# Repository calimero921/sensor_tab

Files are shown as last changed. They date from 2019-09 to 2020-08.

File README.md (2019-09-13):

# sensor_tab
ESP32 sensor tab

External libraries : 
* BLEDevice
* BLEServer
* BLEUtils
* BLE2902
* NDEF: utility class to translate NDEF format of rfid card data (updated and corrected)
* Adafruit_NeoPixel: utility class to manage WS2812 led

Internal libraries : 
* cardReader: wrapper for MFRC522 library mixed with HW-178 multiplexing componenent
* readerState: data and utility class to manage reader state based on rfidData class
* rfidData: data and utility class to manage rfid card information
* pixelManager: wrapper for Adafruit Neo Pixel library to manage the set on WS2812 led, based on readerState library

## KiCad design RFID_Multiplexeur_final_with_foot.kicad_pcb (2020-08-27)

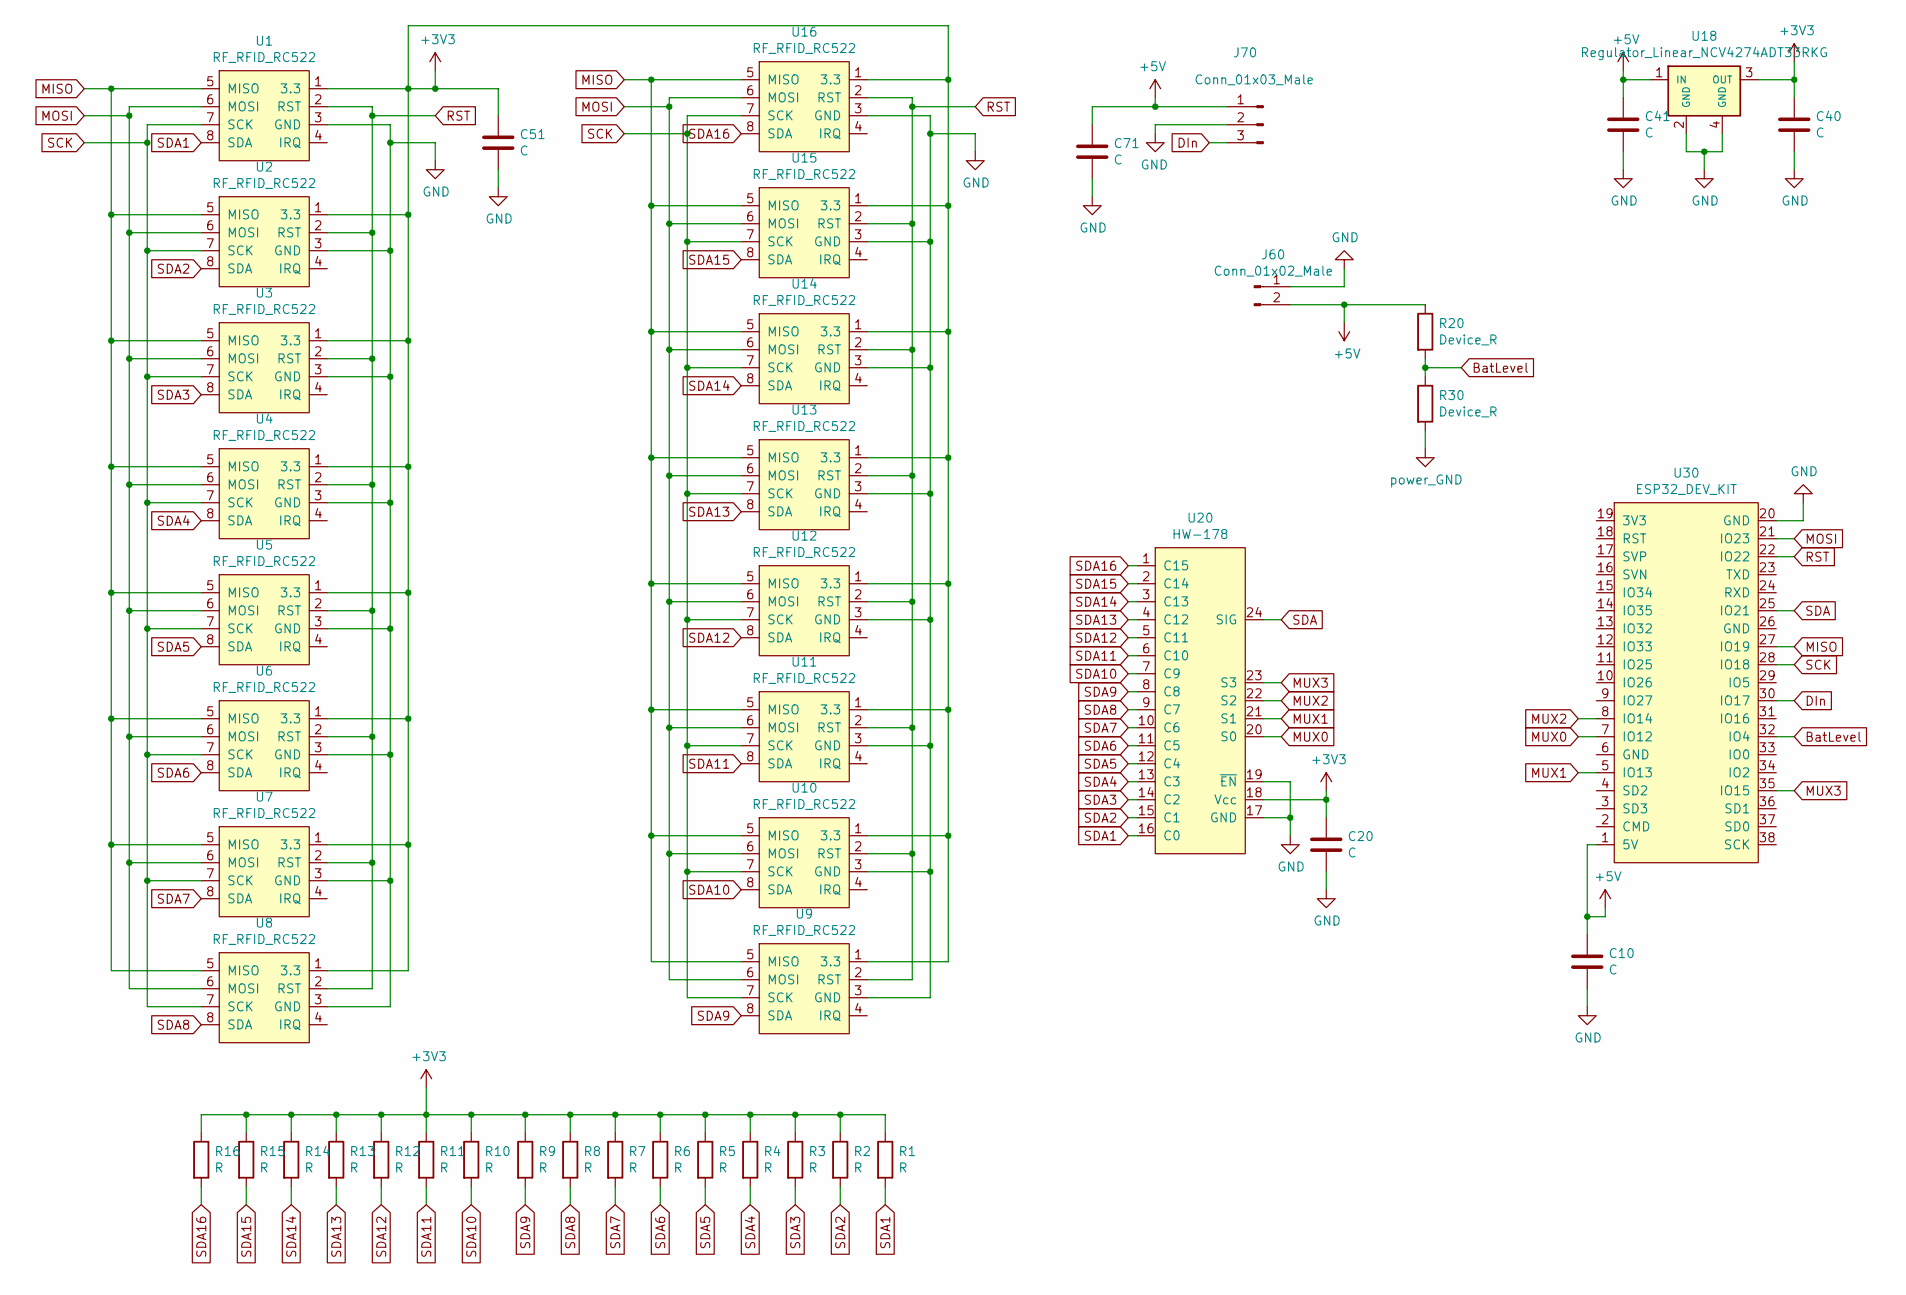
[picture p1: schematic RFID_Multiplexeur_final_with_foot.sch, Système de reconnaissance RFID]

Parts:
C10, C20, C71: C; CP_Radial_D10.0mm_P5.00mm
C40, C41, C51: C; CP_220uF_Eirbot
J60: Conn_01x02_Male; TerminalBlock_bornier-2_P5.08mm
J70: Conn_01x03_Male; JST_PH_S3B-PH-K_1x03_P2.00mm_Horizontal
R1, R2, R3, R4, R5, R6, R7, R8, R9, R10, R11, R12, R13, R14, R15, R16: R; R_Axial_DIN0309_L9.0mm_D3.2mm_P15.24mm_Horizontal
R20, R30: Device_R; R_Axial_DIN0309_L9.0mm_D3.2mm_P15.24mm_Horizontal
U1, U2, U3, U4, U5, U6, U7, U8, U9, U10, U11, U12, U13, U14, U15, U16: RF_RFID_RC522; JST_PH_B8B-PH-SM4-TB_1x08-1MP_P2.00mm_Vertical
U18: Regulator_Linear_NCV4274ADT33RKG; TO-252-3_TabPin4
U20: HW-178; HP4067_Demultiplexer
U30: ESP32_DEV_KIT

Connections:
+3V3: C20.1, C40.1, C51.1, R1.1, R2.1, R3.1, R4.1, R5.1, R6.1, R7.1, R8.1, R9.1, R10.1, R11.1, R12.1, R13.1, R14.1, R15.1, R16.1, U1.1 (3.3), U2.1 (3.3), U3.1 (3.3), U4.1 (3.3), U5.1 (3.3), U6.1 (3.3), U7.1 (3.3), U8.1 (3.3), U9.1 (3.3), U10.1 (3.3), U11.1 (3.3), U12.1 (3.3), U13.1 (3.3), U14.1 (3.3), U15.1 (3.3), U16.1 (3.3), U18.3 (OUT), U20.18 (Vcc); also elsewhere on the board
+5V: C10.1, C41.1, C71.1, J60.2, J70.1, R20.1, U18.1 (IN), U30.1 (5V)
BatLevel: R20.2, R30.1, U30.32 (IO4)
DIn: J70.3, U30.30 (IO17)
MISO: U1.5 (MISO), U2.5 (MISO), U3.5 (MISO), U4.5 (MISO), U5.5 (MISO), U6.5 (MISO), U7.5 (MISO), U8.5 (MISO), U9.5 (MISO), U10.5 (MISO), U11.5 (MISO), U12.5 (MISO), U13.5 (MISO), U14.5 (MISO), U15.5 (MISO), U16.5 (MISO), U30.27 (IO19); also elsewhere on the board
MOSI: U1.6 (MOSI), U2.6 (MOSI), U3.6 (MOSI), U4.6 (MOSI), U5.6 (MOSI), U6.6 (MOSI), U7.6 (MOSI), U8.6 (MOSI), U9.6 (MOSI), U10.6 (MOSI), U11.6 (MOSI), U12.6 (MOSI), U13.6 (MOSI), U14.6 (MOSI), U15.6 (MOSI), U16.6 (MOSI), U30.21 (IO23); also elsewhere on the board
MUX0: U20.20 (S0), U30.7 (IO12)
MUX1: U20.21 (S1), U30.5 (IO13)
MUX2: U20.22 (S2), U30.8 (IO14)
MUX3: U20.23 (S3), U30.35 (IO15)
RST: U1.2 (RST), U2.2 (RST), U3.2 (RST), U4.2 (RST), U5.2 (RST), U6.2 (RST), U7.2 (RST), U8.2 (RST), U9.2 (RST), U10.2 (RST), U11.2 (RST), U12.2 (RST), U13.2 (RST), U14.2 (RST), U15.2 (RST), U16.2 (RST), U30.22 (IO22); also elsewhere on the board
SCK: U1.7 (SCK), U2.7 (SCK), U3.7 (SCK), U4.7 (SCK), U5.7 (SCK), U6.7 (SCK), U7.7 (SCK), U8.7 (SCK), U9.7 (SCK), U10.7 (SCK), U11.7 (SCK), U12.7 (SCK), U13.7 (SCK), U14.7 (SCK), U15.7 (SCK), U16.7 (SCK), U30.28 (IO18); also elsewhere on the board
SDA: U20.24 (SIG), U30.25 (IO21)
SDA1: R1.2, U1.8 (SDA), U20.16 (C0)
SDA2: R2.2, U2.8 (SDA), U20.15 (C1)
SDA3: R3.2, U3.8 (SDA), U20.14 (C2)
SDA4: R4.2, U4.8 (SDA), U20.13 (C3)
SDA5: R5.2, U5.8 (SDA), U20.12 (C4)
SDA6: R6.2, U6.8 (SDA), U20.11 (C5)
SDA7: R7.2, U7.8 (SDA), U20.10 (C6)
SDA8: R8.2, U8.8 (SDA), U20.9 (C7); also elsewhere on the board
SDA9: R9.2, U9.8 (SDA), U20.8 (C8)
SDA10: R10.2, U10.8 (SDA), U20.7 (C9)
SDA11: R11.2, U11.8 (SDA), U20.6 (C10); also elsewhere on the board
SDA12: R12.2, U12.8 (SDA), U20.5 (C11)
SDA13: R13.2, U13.8 (SDA), U20.4 (C12)
SDA14: R14.2, U14.8 (SDA), U20.3 (C13)
SDA15: R15.2, U15.8 (SDA), U20.2 (C14)
SDA16: R16.2, U16.8 (SDA), U20.1 (C15)

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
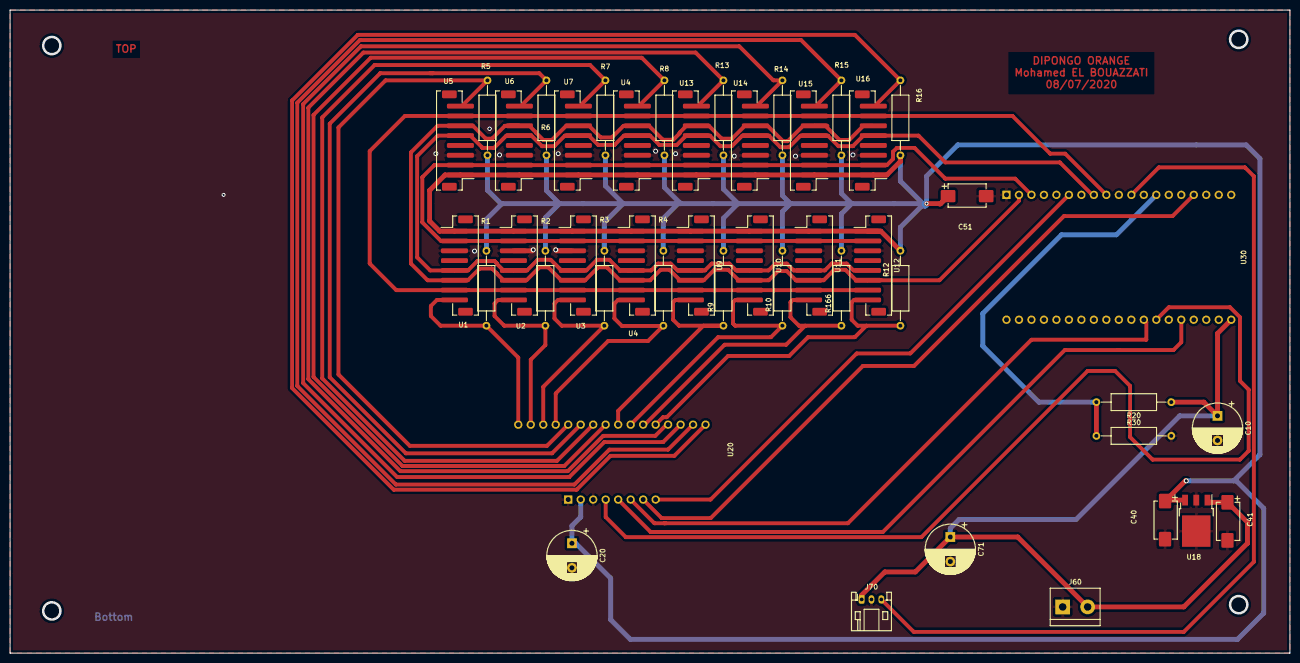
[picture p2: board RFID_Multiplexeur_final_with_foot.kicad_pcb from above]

Board: 2 copper layers, 260.4 x 130.8 mm, 45 parts (0 on the bottom side), 30 nets.

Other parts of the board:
R166: R; R_Axial_DIN0309_L9.0mm_D3.2mm_P15.24mm_Horizontal
U4#2: RF_RFID_RC522; JST_PH_B8B-PH-SM4-TB_1x08-1MP_P2.00mm_Vertical

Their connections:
+3V3: R166.1, U4#2.1; also elsewhere on the board
MISO: U4#2.5; also elsewhere on the board
MOSI: U4#2.6; also elsewhere on the board
RST: U4#2.2; also elsewhere on the board
SCK: U4#2.7; also elsewhere on the board
SDA8: U4#2.8; also elsewhere on the board
SDA11: R166.2; also elsewhere on the board

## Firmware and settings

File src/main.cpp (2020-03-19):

/*
*/

#include <Arduino.h>
#include <BLEDevice.h>
#include <BLEServer.h>
#include <BLEUtils.h>
#include <BLE2902.h>

#include "main.h"
#include "cardReader.h"
#include "rfidData.h"
#include "pixelManager.h"
#include "readerState.h"

BLEServer *pServer = NULL;
BLECharacteristic *pLedCharacteristic = NULL;
BLECharacteristic *pRfidCharacteristic = NULL;
bool deviceConnected = false;
bool oldDeviceConnected = false;
uint32_t value = 0;

int manufacturer_code = 0xFFFF;
char manufacturer_name[] = "DIPONGO";
char device_name[] = "DIPONGO-TAB-ESP32";

// Configuration readerState
ReaderState readerState = ReaderState(MFRC522COUNT);

// Configuration Adafruit_NeoPixel
// Adafruit_NeoPixel pixels(PIXELNUMBER, PIXELDATAPIN, NEO_GRB + NEO_KHZ800);
PixelManager pixelStrip = PixelManager(PIXELCOUNT);

// Configuration MFRC522
CardReader cardReader = CardReader(MFRC522COUNT);

BLEAdvertisementData advertisement;
BLEAdvertising *pAdvertising;

class MyServerCallbacks : public BLEServerCallbacks
{
  void onConnect(BLEServer *pServer)
  {
    deviceConnected = true;
    BLEDevice::startAdvertising();
  };

  void onDisconnect(BLEServer *pServer)
  {
    deviceConnected = false;
  }
};

class LedCharacteristicCallbacks : public BLECharacteristicCallbacks
{
  void onRead(BLECharacteristic *pCharacteristic)
  {
    String jsonString = readerState.toJsonString(true, false);
    uint16_t arraySize = jsonString.length();
    char results[arraySize];
    jsonString.toCharArray(results, arraySize);
    pCharacteristic->setValue(results);
  }

  void onWrite(BLECharacteristic *pCharacteristic)
  {
    std::string value = pCharacteristic->getValue();
    Serial.print("Received Value: ");
    for (int i = 0; i < value.length(); i++)
      Serial.print(value[i]);
    Serial.println();
  }
};

class RfidCharacteristicCallbacks : public BLECharacteristicCallbacks
{
  void onRead(BLECharacteristic *pCharacteristic)
  {
    String jsonString = readerState.toJsonString(true, true);
    uint16_t arraySize = jsonString.length();
    char results[arraySize];
    jsonString.toCharArray(results, arraySize);
    pCharacteristic->setValue(results);
  }
};

void setup()
{
  Serial.begin(115200);
  Serial.println("Main::Setup");

  pixelStrip.init();
  pixelStrip.switchOffAllPixels();

  cardReader.init();

  // Create the BLE Device
  BLEDevice::init(device_name);

  // Create the BLE Server
  pServer = BLEDevice::createServer();
  pAdvertising = pServer->getAdvertising();

  String s;
  char b2 = (char)(manufacturer_code >> 8);
  manufacturer_code <<= 8;
  char b1 = (char)(manufacturer_code >> 8);
  s.concat(b1);
  s.concat(b2);
  s.concat(manufacturer_name);
  advertisement.setManufacturerData(s.c_str());
  advertisement.setName(device_name);
  pAdvertising->setAdvertisementData(advertisement);
  pServer->setCallbacks(new MyServerCallbacks());

  // Create the BLE Service
  BLEService *pService = pServer->createService(SERVICE_UUID);

  // Create a BLE led Characteristic
  pLedCharacteristic = pService->createCharacteristic(
      LED_CHARACTERISTIC_UUID,
      BLECharacteristic::PROPERTY_READ |
          BLECharacteristic::PROPERTY_WRITE |
          BLECharacteristic::PROPERTY_NOTIFY |
          BLECharacteristic::PROPERTY_INDICATE);
  // https://www.bluetooth.com/specifications/gatt/viewer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
  // Create a BLE Descriptor
  pLedCharacteristic->addDescriptor(new BLE2902());
  pLedCharacteristic->setCallbacks(new LedCharacteristicCallbacks());

  // Create a BLE led Characteristic
  pRfidCharacteristic = pService->createCharacteristic(
      RFID_CHARACTERISTIC_UUID,
      BLECharacteristic::PROPERTY_READ |
          BLECharacteristic::PROPERTY_NOTIFY |
          BLECharacteristic::PROPERTY_INDICATE);
  // https://www.bluetooth.com/specifications/gatt/viewer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
  // Create a BLE Descriptor
  pRfidCharacteristic->addDescriptor(new BLE2902());
  pRfidCharacteristic->setCallbacks(new RfidCharacteristicCallbacks());

  // Start the service
  pService->start();

  // Start advertising
  BLEAdvertising *pAdvertising = BLEDevice::getAdvertising();
  pAdvertising->addServiceUUID(SERVICE_UUID);
  pAdvertising->setScanResponse(false);
  pAdvertising->setMinPreferred(0x0); // set value to 0x00 to not advertise this parameter
  BLEDevice::startAdvertising();
  Serial.println("Main::Waiting a client connection to notify...");
}

void loop()
{
  // notify changed value
  if (deviceConnected)
  {
#ifdef DEBUG
    Serial.println("Main::Device connected...");
#endif
    boolean hasChanged = false;
    for (int reader = 0; reader < MFRC522COUNT; reader++)
    {
#ifdef DEBUG
      Serial.print("Main::Using reader ");
      Serial.print(reader);
      Serial.println(" ...");
#endif
      RfidData cardContent = cardReader.readRFIDCard(reader);
      // test if reader has content
      if (cardContent.error().length() == 0)
      {
        if (readerState.setState(reader, &cardContent))
        {
          hasChanged = true;
        }
      }
    }
    //pixelStrip.setPixelState(&readerState);

    if (hasChanged)
    {
      String jsonString = readerState.toJsonString(true, true);
      uint16_t arraySize = jsonString.length();
      char results[arraySize];
      jsonString.toCharArray(results, arraySize);

      Serial.print("Main::Notifying bluetooth master:");
      Serial.println(results);
      pRfidCharacteristic->setValue(results);
      pRfidCharacteristic->notify();
    }
    else
    {
#ifdef DEBUG
      Serial.println("Main::Nothing to notify...");
#endif
    }
    // delay(1000);
  }

  // disconnecting
  if (!deviceConnected && oldDeviceConnected)
  {
    Serial.println("Main::Device disconnecting...");
    delay(500); // give the bluetooth stack the chance to get things ready

    cardReader.shutdownAllReaders();
    pixelStrip.switchOffPixel(PIXELCOUNT - 1);

    pAdvertising->start();
    Serial.println("Main::Start advertising");
    oldDeviceConnected = deviceConnected;
  }
  // connecting
  if (deviceConnected && !oldDeviceConnected)
  {
    Serial.println("Main::Device connecting...");
    //pixelStrip.setPixelRGB(PIXELCOUNT - 1, 0, 32, 0);
    // do stuff here on connecting
    oldDeviceConnected = deviceConnected;
  }
}

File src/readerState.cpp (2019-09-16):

/*
*/

#include "readerState.h"

ReaderState::ReaderState(int nbCardReader)
{
    countCardReader = nbCardReader;
    readerState = (RfidData *)calloc(countCardReader, sizeof(RfidData));
    // Initialisation du tableau
    for(uint16_t i = 0; i < countCardReader; i++)
    {
        readerState[i] = RfidData();
    }
}

ReaderState::~ReaderState()
{
    free(readerState);
}

uint16_t ReaderState::count()
{
    return countCardReader;
}

boolean ReaderState::setState(uint16_t reader, RfidData *data)
{
#ifdef DEBUG
    Serial.println("ReaderState::setState:");
#endif
    boolean result = true;
    if (data->error().length() > 0)
    {
        // do not change state if an error occurs
        result = false;
    }
    else
    {
        if (readerState[reader].equals(data))
        {
            // do not change state if data is the same
            result = false;
        }
        else
        {
            // update state if data is different
            readerState[reader].set(data);
        }
    }
#ifdef DEBUG
    Serial.print("ReaderState::setState:return ");
    Serial.println(result);
#endif
    return result;
}

RfidData ReaderState::getState(uint16_t reader)
{
    return readerState[reader];
}

String ReaderState::toJsonString(boolean colorSelector, boolean formatSelector)
{
    StaticJsonDocument<1024> jsonArray;

    for (int reader = 0; reader < countCardReader; reader++)
    {
        StaticJsonDocument<256> jsonObject;
        jsonObject["reader"] = reader;
        if (colorSelector)
        {
            jsonObject["color"] = readerState[reader].color();
        }
        if (formatSelector)
        {
            jsonObject["format"] = readerState[reader].format();
        }
#ifdef DEBUG
        Serial.print("toJsonString::jsonObject -> ");
        serializeJson(jsonObject, Serial);
        Serial.println();
#endif
        jsonArray.add(jsonObject);
    }
    uint16_t arraySize = jsonArray.memoryUsage();
#ifdef DEBUG
    Serial.print("toJsonString::arraySize -> ");
    Serial.println(arraySize);
#endif
    char results[arraySize];
    serializeJson(jsonArray, results, arraySize);
#ifdef DEBUG
    Serial.print("toJsonString::result -> ");
    Serial.println(results);
#endif
    return String(results);
}

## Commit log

2019-05-14 Update main.cpp
    Add WS2812 driver
    Add MFRC522 driver
2019-07-03 Mise à jour lecture de tag et interprétation couleur
2019-07-11 Prise en charge multiplexeur
2019-09-13 Mise à jour .gitignore préparation commentaire en tête de fichier
2019-09-13 Mise à jour affichage des logs de debug
2020-03-19 Update for prototype
